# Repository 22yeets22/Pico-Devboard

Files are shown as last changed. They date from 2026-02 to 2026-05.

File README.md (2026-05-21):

<h1 align="center">
  Pico+ Devboard
  <br>
</h1>

<h4 align="center">
A pico sized custom rp2040 devboard, but with 16MB flash and a lot of extra features!
</h4>
<br>

<div align="center">
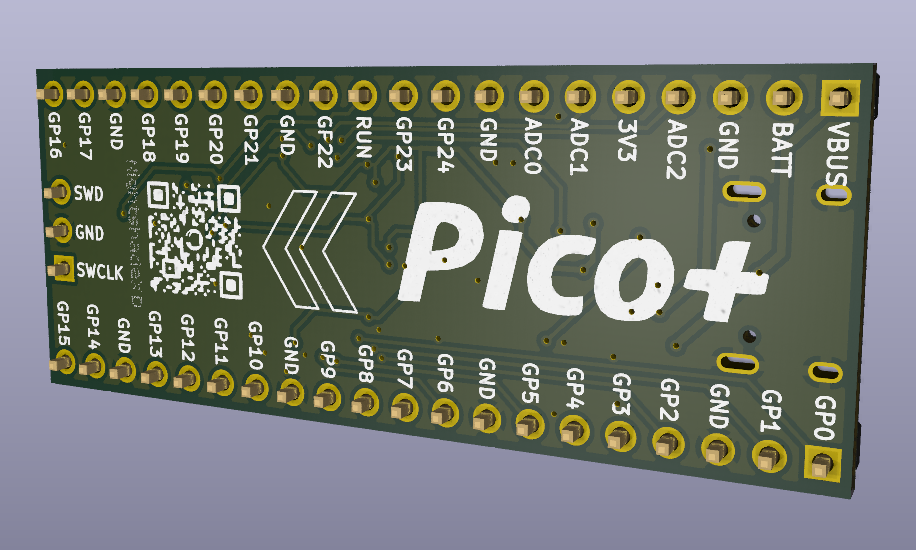
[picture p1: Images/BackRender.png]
Back Render


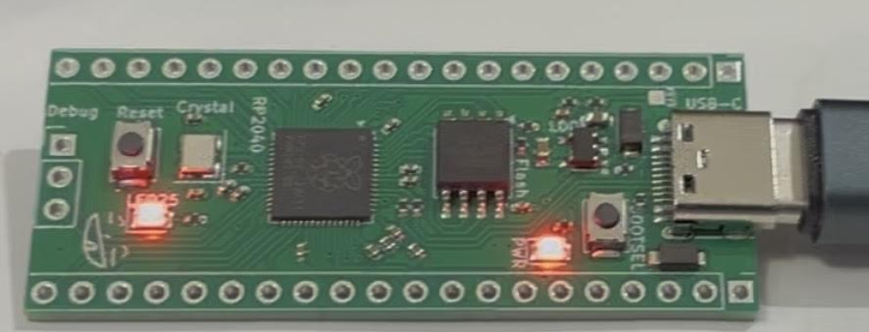
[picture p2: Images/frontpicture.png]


| Front Render | PCB |
| --- | --- |
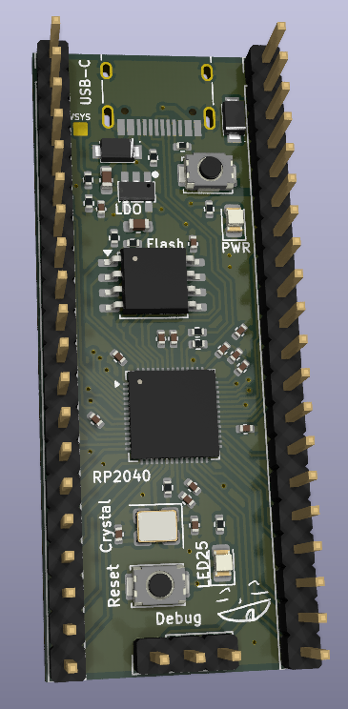
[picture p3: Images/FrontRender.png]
Front Render
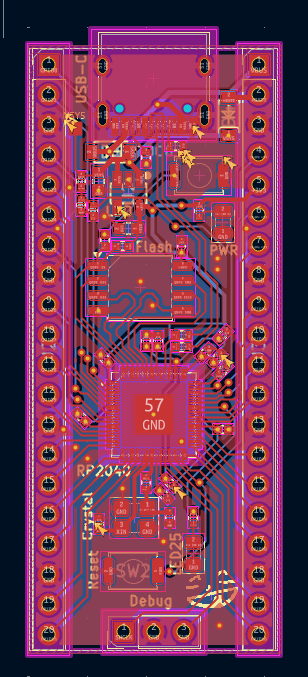
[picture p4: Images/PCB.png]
PCB
|  |  |

</div>

## Motivation

I wanted a more capable RP2040 board with significantly more flash memory and USB-C. Most dev boards limit storage and input options, so I designed one that supports USB-C, battery input, higher current capability, and voltage monitoring while staying in the same form factor.

## Features

- RP2040 microcontroller
- 16MB QSPI Flash
- USB-C
- Battery input (Schottky diode OR-ing with USB)
- 500mA LDO (10V max input)
- VSYS voltage monitoring via resistor divider on ADC3
- Onboard power LED
- Onboard GPIO25 LED
- Bootsel + Reset button
- Fully labeled GPIO pins

## Future Improvements

- Buck-boost regulator for better efficiency + larger voltage range
- Exposed VSYS pin
- 3V3_EN pin breakout

## How to Use

Like a normal Pico:

1. Power the board via USB-C or VBAT input.
2. Flash firmware using BOOTSEL mode (or make your own)
3. Use onboard GPIO headers as you would with a standard Pico.

## Firmware

Untested waveshare 16mb - not my firmware, but has similar specs, so should work fine. Runs circuitpython.

## BOM

A complete `BOM.csv` with direct links is provided in BOM.csv in the root directory.
| Designator | Comment | Footprint | Manufacturer | Part Number | JLCPCB Part # | Link | Qty | Total Price ($) |
|---|---|---|---|---|---|---|-----|---|
| C1, C4 | 1uF | 0402 | Samsung | CL05A105KA5NQNC | C52923 | https://jlcpcb.com/partdetail/53938-CL05A105KA5NQNC/C52923 | 10 | 0.033 |
| C9 | 1nF | 0402 | FH | 0402B102K500NT | C1523 | https://jlcpcb.com/partdetail/1875-0402B102K500NT/C1523 | 5 | 0.006 |
| C11, C8, C3, C10, C17, C5, C7, C6, C12, C2 | 0.1uF | 0402 | Samsung | CL05B104KO5NNNC | C1525 | https://jlcpcb.com/partdetail/1877-CL05B104KO5NNNC/C1525 | 50 | 0.065 |
| C14, C13 | 10uF | 0603 | Samsung | CL10A106KP8NNNC | C19702 | https://jlcpcb.com/partdetail/20411-CL10A106KP8NNNC/C19702 | 10 | 0.065 |
| C16, C15 | 33pF | 0402 | FH | 0402CG330J500NT | C1562 | https://jlcpcb.com/partdetail/1914-0402CG330J500NT/C1562 | 10 | 0.012 |
| D2, D1 | LED (Red 0805) | 0805 | NationStar | NCD0805R1 | C84256 | https://jlcpcb.com/partdetail/85425-NCD0805R1/C84256 | 10 | 0.131 |
| D4, D3 | FMBR120VLSFT1G | SOD-123FL | FUXINSEMI | FMBR120VLSFT1G | C48677824 | https://jlcpcb.com/partdetail/FUXINSEMI-FMBR120VLSFT1G/C48677824 | 14 | 1.0444 |
| J1 | USB-C 14P | SMD | Hroparts | TYPE-C-31-M-12 | C165948 | https://jlcpcb.com/partdetail/Korean_HropartsElec-TYPE_C_31_M12/C165948 | 5 | 0.9055 |
| R1, R2 | 5.1K | 0402 | UNI-ROYAL | 0402WGF5101TCE | C25905 | https://jlcpcb.com/partdetail/26648-0402WGF5101TCE/C25905 | 10 | 0.008 |
| R4, R3 | 27Ω | 0402 | UNI-ROYAL | 0402WGF270JTCE | C25100 | https://jlcpcb.com/partdetail/25843-0402WGF270JTCE/C25100 | 22 | 0.0154 |
| R7 | 10K | 0402 | UNI-ROYAL | 0402WGF1002TCE | C25744 | https://jlcpcb.com/partdetail/26487-0402WGF1002TCE/C25744 | 5 | 0.004 |
| R9, R8, R5, R6 | 1K | 0402 | UNI-ROYAL | 0402WGF1001TCE | C11702 | https://jlcpcb.com/partdetail/12256-0402WGF1001TCE/C11702 | 20 | 0.014 |
| R10 | 200K | 0402 | UNI-ROYAL | 0402WGF2003TCE | C25764 | https://jlcpcb.com/partdetail/26507-0402WGF2003TCE/C25764 | 5 | 0.0035 |
| R11 | 100K | 0402 | UNI-ROYAL | 0402WGF1003TCE | C25741 | https://jlcpcb.com/partdetail/26484-0402WGF1003TCE/C25741 | 5 | 0.004 |
| SW2, SW1 | Tactile Switch | 4x3mm SMD | XUNPU | TS-1088-AR02016 | C720477 | https://jlcpcb.com/partdetail/XUNPU-TS_1088AR02016/C720477 | 10 | 0.476 |
| U1 | RP2040 | LQFN-56 | Raspberry Pi | RP2040 | C2040 | https://jlcpcb.com/partdetail/RaspberryPi-RP2040/C2040 | 5 | 4.827 |
| U2 | TPSPX3819M5-L-3-3 | SOT-23-5 | TECH PUBLIC | TPSPX3819M5-L-3-3 | C5370980 | https://jlcpcb.com/partdetail/TECHPUBLIC-TPSPX3819M5_L_33/C5370980 | 7 | 0.6839 |
| U3 | W25Q128JVSIQ | SOIC-8-208mil | Winbond | W25Q128JVSIQ | C97521 | https://jlcpcb.com/partdetail/WinbondElec-W25Q128JVSIQ/C97521 | 5 | 11.637 |
| Y1 | 12MHz Crystal | SMD3225-4P | YXC | X322512MSB4SI | C9002 | https://jlcpcb.com/partdetail/YXC_CrystalOscillators-X322512MSB4SI/C9002 | 5 | 0.363 |
| J3, J2 | 1x20 Pin Header | P2.54mm | — | Not Selected | — | — | — | — |
| J4 | 1x03 Pin Header | P2.54mm | — | Not Selected | — | — | — | — |

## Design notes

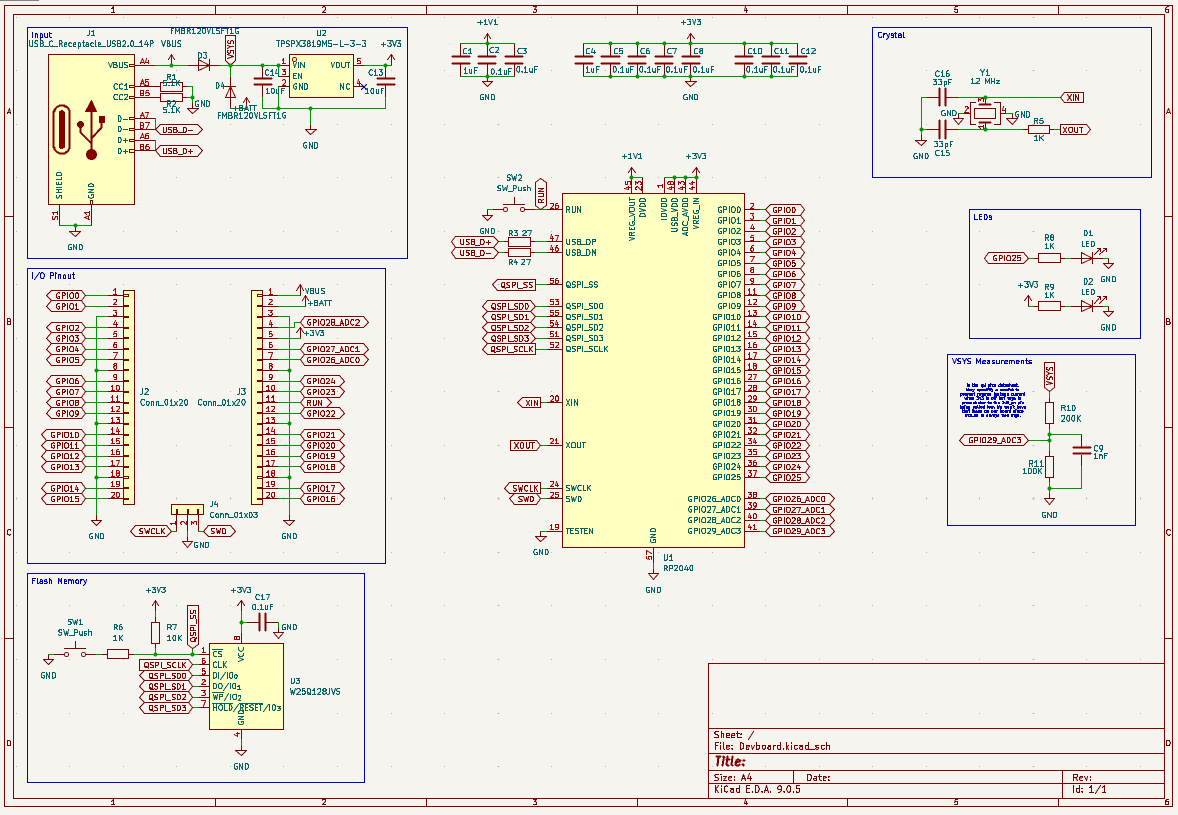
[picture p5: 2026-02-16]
Images/Schematic.png

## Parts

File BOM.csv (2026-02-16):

Id | Designator | Footprint | Quantity | Comment | Supplier and ref
1 | SW2,SW1 | SW_Push_SPST_NO_Alps_SKRK | 2 | SW_Push
2 | C16,C15 | C_0402_1005Metric | 2 | 33pF
3 | U2 | SOT-23-5_L3.0-W1.6-P0.95-LS2.8-BR | 1 | TPSPX3819M5-L-3-3
4 | R11 | R_0402_1005Metric | 1 | 100K
5 | R10 | R_0402_1005Metric | 1 | 200K
6 | D4,D3 | SOD-123FL_L2.8-W1.8-LS3.8-RD | 2 | FMBR120VLSFT1G
7 | C9 | C_0402_1005Metric | 1 | 1nF
8 | J1 | USB_C_Receptacle_HRO_TYPE-C-31-M-12 | 1 | USB_C_Receptacle_USB2.0_14P
9 | C11,C8,C3,C10,C17,C5,C7,C6,C12,C2 | C_0402_1005Metric | 10 | 0.1uF
10 | R4,R3 | R_0402_1005Metric | 2 | 27
11 | C1,C4 | C_0402_1005Metric | 2 | 1uF
12 | R1,R2 | R_0402_1005Metric | 2 | 5.1K
13 | J4 | PinHeader_1x03_P2.54mm_Vertical | 1 | Conn_01x03
14 | C14,C13 | C_0603_1608Metric | 2 | 10uF
15 | D2,D1 | LED_0805_2012Metric | 2 | LED
16 | R7 | R_0402_1005Metric | 1 | 10K
17 | R9,R8,R5,R6 | R_0402_1005Metric | 4 | 1K
18 | J3,J2 | PinHeader_1x20_P2.54mm_Vertical | 2 | Conn_01x20
19 | Y1 | Crystal_SMD_3225-4Pin_3.2x2.5mm | 1 | 12 MHz
20 | U1 | QFN-56-1EP_7x7mm_P0.4mm_EP3.2x3.2mm | 1 | RP2040
21 | U3 | SOIC-8_5.3x5.3mm_P1.27mm | 1 | W25Q128JVS

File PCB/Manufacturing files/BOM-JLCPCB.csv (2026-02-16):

JLCPCB BOM Tool - BOM Matching
BOM name?Devboard-JLCPCB Assembly Order.xlsx |  |  | Download Time?2026-02-16 22:46:35 |  |  |  | * Our matching results are updated in real-time, but stock and prices may change. If it's been over 24 hours, please re-match before placing your order.
PCB Assembled Qty?5 |  |  | Est. Total Price?20.2977
Your BOM |  |  |  |  | Matched Parts |  |  |  |  |  |  | Order Information
Top Designator | Bottom Designator | Comment | Footprint | JLCPCB Part # | Matches | Part # | Manufacturer | Footprint | Description | Category | Warning | JLCPCB Part # | Product link | Lib Type | Qty | Source | Total Price ($)
C1,C4 |  | 1uF | C_0402_1005Metric |  | Select by Customer | CL05A105KA5NQNC | Samsung Electro-Mechanics | 0402 | 1uF 25V X5R ±10% 0402 Multilayer Ceramic Capacitors MLCC - SMD/SMT ROHS | Multilayer Ceramic Capacitors MLCC - SMD/SMT |  | C52923 | https://jlcpcb.com/partdetail/53938-CL05A105KA5NQNC/C52923 | Basic | 10 | 10 JLCPCB | 0.033
C9 |  | 1nF | C_0402_1005Metric |  | Select by Customer | 0402B102K500NT | FH (Guangdong Fenghua Advanced Tech) | 0402 | 1nF 50V X7R ±10% 0402 Multilayer Ceramic Capacitors MLCC - SMD/SMT ROHS | Multilayer Ceramic Capacitors MLCC - SMD/SMT |  | C1523 | https://jlcpcb.com/partdetail/1875-0402B102K500NT/C1523 | Basic | 5 | 5 JLCPCB | 0.006
C11,C8,C3,C10,C17,C5,C7,C6,C12,C2 |  | 0.1uF | C_0402_1005Metric |  | Select by Customer | CL05B104KO5NNNC | Samsung Electro-Mechanics | 0402 | 100nF 16V X7R ±10% 0402 Multilayer Ceramic Capacitors MLCC - SMD/SMT ROHS | Multilayer Ceramic Capacitors MLCC - SMD/SMT | 1.The comment (CL05B104KO5NNNC) of this part does not match the one (0.1uF) provided in your BOM. Please confirm; | C1525 | https://jlcpcb.com/partdetail/1877-CL05B104KO5NNNC/C1525 | Basic | 50 | 50 JLCPCB | 0.065
C14,C13 |  | 10uF | C_0603_1608Metric |  | Select by Customer | CL10A106KP8NNNC | Samsung Electro-Mechanics | 0603 | 10V 10uF X5R ±10% 0603 Multilayer Ceramic Capacitors MLCC - SMD/SMT ROHS | Multilayer Ceramic Capacitors MLCC - SMD/SMT |  | C19702 | https://jlcpcb.com/partdetail/20411-CL10A106KP8NNNC/C19702 | Basic | 10 | 10 JLCPCB | 0.065
C16,C15 |  | 33pF | C_0402_1005Metric |  | Select by Customer | 0402CG330J500NT | FH (Guangdong Fenghua Advanced Tech) | 0402 | 33pF 50V C0G ±5% 0402 Multilayer Ceramic Capacitors MLCC - SMD/SMT ROHS | Multilayer Ceramic Capacitors MLCC - SMD/SMT |  | C1562 | https://jlcpcb.com/partdetail/1914-0402CG330J500NT/C1562 | Basic | 10 | 10 JLCPCB | 0.012
D2,D1 |  | LED | LED_0805_2012Metric |  | Select by Customer | NCD0805R1 | Foshan NationStar Optoelectronics | 0805 | -30?~+85? 1.6V~2.6V 130° 195mcd 25mA 615nm~630nm 630nm 65mW Discrete Diode Red 0805 LED Indication - Discrete ROHS | LED Indication - Discrete | 1.The comment (NCD0805R1) of this part does not match the one (LED) provided in your BOM. Please confirm; | C84256 | https://jlcpcb.com/partdetail/85425-NCD0805R1/C84256 | Basic | 10 | 10 JLCPCB | 0.131
D4,D3 |  | FMBR120VLSFT1G | SOD-123FL_L2.8-W1.8-LS3.8-RD |  | Select by System | FMBR120VLSFT1G | FUXINSEMI | SOD-123FL | -55?~+125? 1A 200uA 20V 380mV@1.0A 45A SOD-123FL Super Barrier Rectifiers (SBR) ROHS | Super Barrier Rectifiers (SBR) |  | C48677824 | https://jlcpcb.com/partdetail/FUXINSEMI-FMBR120VLSFT1G/C48677824 | Extended | 14 | 14 JLCPCB | 1.0444
J1 |  | USB_C_Receptacle_USB2.0_14P | USB_C_Receptacle_HRO_TYPE-C-31-M-12 |  | Select by Customer | TYPE-C-31-M-12 | Korean Hroparts Elec | SMD | -30?~+80? 1 10,000 cycles 16P 20V 5A 7.35mm Female Surface Mount, Right Angle Type-C SMD USB Connectors ROHS | USB Connectors |  | C165948 | https://jlcpcb.com/partdetail/Korean_HropartsElec-TYPE_C_31_M12/C165948 | Extended | 5 | 5 JLCPCB | 0.9055
R1,R2 |  | 5.1K | R_0402_1005Metric |  | Select by Customer | 0402WGF5101TCE | UNI-ROYAL(Uniroyal Elec) | 0402 | -55?~+155? 5.1k? 50V 62.5mW Thick Film Resistor ±1% ±100ppm/? 0402 Chip Resistor - Surface Mount ROHS | Chip Resistor - Surface Mount |  | C25905 | https://jlcpcb.com/partdetail/26648-0402WGF5101TCE/C25905 | Basic | 10 | 10 JLCPCB | 0.008
R4,R3 |  | 27 | R_0402_1005Metric |  | Select by Customer | 0402WGF270JTCE | UNI-ROYAL(Uniroyal Elec) | 0402 | -55?~+155? 27? 50V 62.5mW Thick Film Resistor ±1% ±100ppm/? 0402 Chip Resistor - Surface Mount ROHS | Chip Resistor - Surface Mount | 1.The comment (0402WGF270JTCE) of this part does not match the one (27) provided in your BOM. Please confirm; | C25100 | https://jlcpcb.com/partdetail/25843-0402WGF270JTCE/C25100 | Extended | 22 | 22 JLCPCB | 0.0154
R7 |  | 10K | R_0402_1005Metric |  | Select by Customer | 0402WGF1002TCE | UNI-ROYAL(Uniroyal Elec) | 0402 | -55?~+155? 10k? 50V 62.5mW Thick Film Resistor ±1% ±100ppm/? 0402 Chip Resistor - Surface Mount ROHS | Chip Resistor - Surface Mount | 1.The comment (0402WGF1002TCE) of this part does not match the one (10K) provided in your BOM. Please confirm; | C25744 | https://jlcpcb.com/partdetail/26487-0402WGF1002TCE/C25744 | Basic | 5 | 5 JLCPCB | 0.004
R9,R8,R5,R6 |  | 1K | R_0402_1005Metric |  | Select by Customer | 0402WGF1001TCE | UNI-ROYAL(Uniroyal Elec) | 0402 | -55?~+155? 1k? 50V 62.5mW Thick Film Resistor ±1% ±100ppm/? 0402 Chip Resistor - Surface Mount ROHS | Chip Resistor - Surface Mount | 1.The comment (0402WGF1001TCE) of this part does not match the one (1K) provided in your BOM. Please confirm; | C11702 | https://jlcpcb.com/partdetail/12256-0402WGF1001TCE/C11702 | Basic | 20 | 20 JLCPCB | 0.014
R10 |  | 200K | R_0402_1005Metric |  | Select by Customer | 0402WGF2003TCE | UNI-ROYAL(Uniroyal Elec) | 0402 | -55?~+155? 200k? 50V 62.5mW Thick Film Resistor ±1% ±100ppm/? 0402 Chip Resistor - Surface Mount ROHS | Chip Resistor - Surface Mount | 1.The comment (0402WGF2003TCE) of this part does not match the one (200K) provided in your BOM. Please confirm; | C25764 | https://jlcpcb.com/partdetail/26507-0402WGF2003TCE/C25764 | Basic | 5 | 5 JLCPCB | 0.0035
R11 |  | 100K | R_0402_1005Metric |  | Select by Customer | 0402WGF1003TCE | UNI-ROYAL(Uniroyal Elec) | 0402 | -55?~+155? 100k? 50V 62.5mW Thick Film Resistor ±1% ±100ppm/? 0402 Chip Resistor - Surface Mount ROHS | Chip Resistor - Surface Mount | 1.The comment (0402WGF1003TCE) of this part does not match the one (100K) provided in your BOM. Please confirm; | C25741 | https://jlcpcb.com/partdetail/26484-0402WGF1003TCE/C25741 | Basic | 5 | 5 JLCPCB | 0.004
SW2,SW1 |  | SW_Push | SW_Push_SPST_NO_Alps_SKRK |  | Select by Customer | TS-1088-AR02016 | XUNPU | SMD,4x3mm | -30?~+80? 1.6N 100,000 Cycles 12V 2mm 3mm 4mm 50mA Black Round Button SMD(SMT) Tab SPST Surface Mount,Vertical Without Bracket SMD,4x3mm Tactile Switches ROHS | Tactile Switches |  | C720477 | https://jlcpcb.com/partdetail/XUNPU-TS_1088AR02016/C720477 | Basic | 10 | 10 JLCPCB | 0.476
U1 |  | RP2040 | QFN-56-1EP_7x7mm_P0.4mm_EP3.2x3.2mm |  | Select by Customer | RP2040 | Raspberry Pi | LQFN-56(7x7) | 12bit 133MHz 30 LQFN-56(7x7) Microcontrollers (MCU/MPU/SOC) ROHS | Microcontrollers (MCU/MPU/SOC) |  | C2040 | https://jlcpcb.com/partdetail/RaspberryPi-RP2040/C2040 | Extended | 5 | 5 JLCPCB | 4.827
U2 |  | TPSPX3819M5-L-3-3 | SOT-23-5_L3.0-W1.6-P0.95-LS2.8-BR |  | Select by System | TPSPX3819M5-L-3-3 | TECH PUBLIC | SOT-23-5 | -40?~+125?@(Tj) 1 20V 3.3V 420mV@(100mA) 500mA 5uA 70dB@(1kHz) Fixed Over Current Protection?Over Temperature Protection?Enable Positive SOT-23-5 Voltage Regulators - Linear, Low Drop Out (LDO) Regulators ROHS | Voltage Regulators - Linear, Low Drop Out (LDO) Regulators |  | C5370980 | https://jlcpcb.com/partdetail/TECHPUBLIC-TPSPX3819M5_L_33/C5370980 | Extended | 7 | 7 JLCPCB | 0.6839
U3 |  | W25Q128JVS | SOIC-8_5.3x5.3mm_P1.27mm |  | Select by Customer | W25Q128JVSIQ | Winbond Elec | SOIC-8-208mil | -40?~+85? 100,000 Cycles 120ms@(32KB) 128Mbit 133MHz 1uA 2.7V~3.6V 20 Years 3ms SPI SOIC-8-208mil NOR FLASH ROHS | NOR FLASH | 1.The comment (W25Q128JVSIQ) of this part does not match the one (W25Q128JVS) provided in your BOM. Please confirm; | C97521 | https://jlcpcb.com/partdetail/WinbondElec-W25Q128JVSIQ/C97521 | Basic | 5 | 5 JLCPCB | 11.637
Y1 |  | 12MHz | Crystal_SMD_3225-4Pin_3.2x2.5mm |  | Select by Customer | X322512MSB4SI | YXC Crystal Oscillators | SMD3225-4P | -40?~+85? 12MHz 20pF Crystal Oscillator ±10ppm ±20ppm SMD3225-4P Crystals ROHS | Crystals |  | C9002 | https://jlcpcb.com/partdetail/YXC_CrystalOscillators-X322512MSB4SI/C9002 | Basic | 5 | 5 JLCPCB | 0.363
J3,J2 |  | Conn_01x20 | PinHeader_1x20_P2.54mm_Vertical |  | No matches | No Part Selected
J4 |  | Conn_01x03 | PinHeader_1x03_P2.54mm_Vertical |  | No matches | No Part Selected

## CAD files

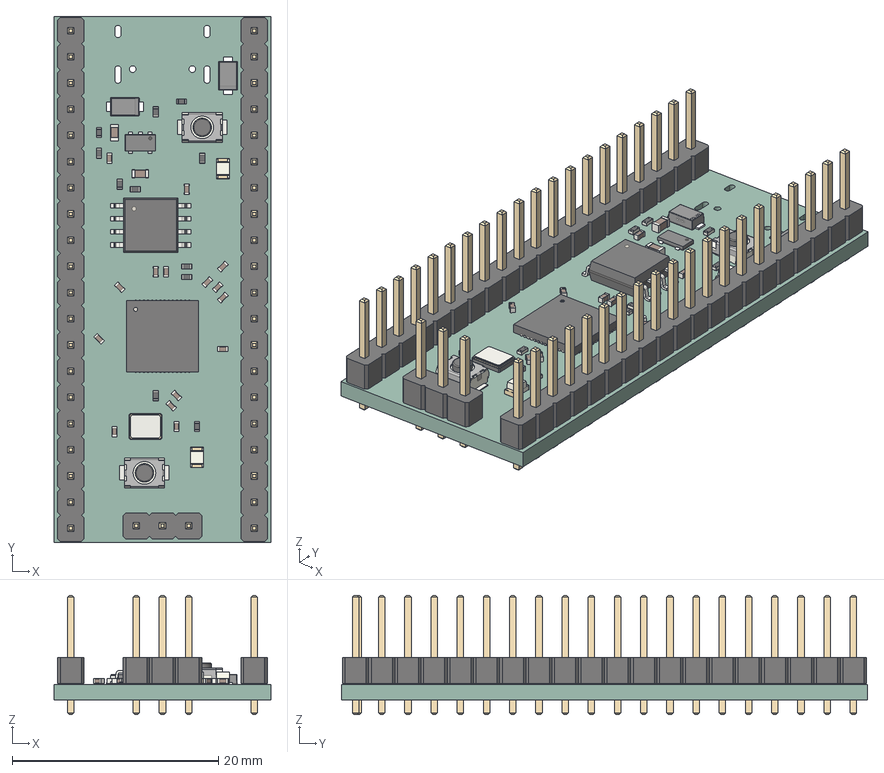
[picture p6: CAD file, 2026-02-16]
Devboard.step
21.0 x 51.0 x 11.5 mm
C_0402_1005Metric x 15
SOD-123FL_L2.8-W1.8-LS3.8-RD x 2
R_0402_1005Metric x 11
PinHeader_1x03_P2.54mm_Vertical
C_0603_1608Metric x 2
LED_0805_2012Metric x 2
SOT-23-5_L3.0-W1.6-P0.95-LS2.8-BR
SW_Push_SPST_NO_Alps_SKRK x 2
PinHeader_1x20_P2.54mm_Vertical x 2
Crystal_SMD_3225-4Pin_3.2x2.5mm
QFN-56-1EP_7x7mm_P0.4mm_EP3.2x3.2mm
SOIC-8_5.3x5.3mm_P1.27mm
Devboard_PCB

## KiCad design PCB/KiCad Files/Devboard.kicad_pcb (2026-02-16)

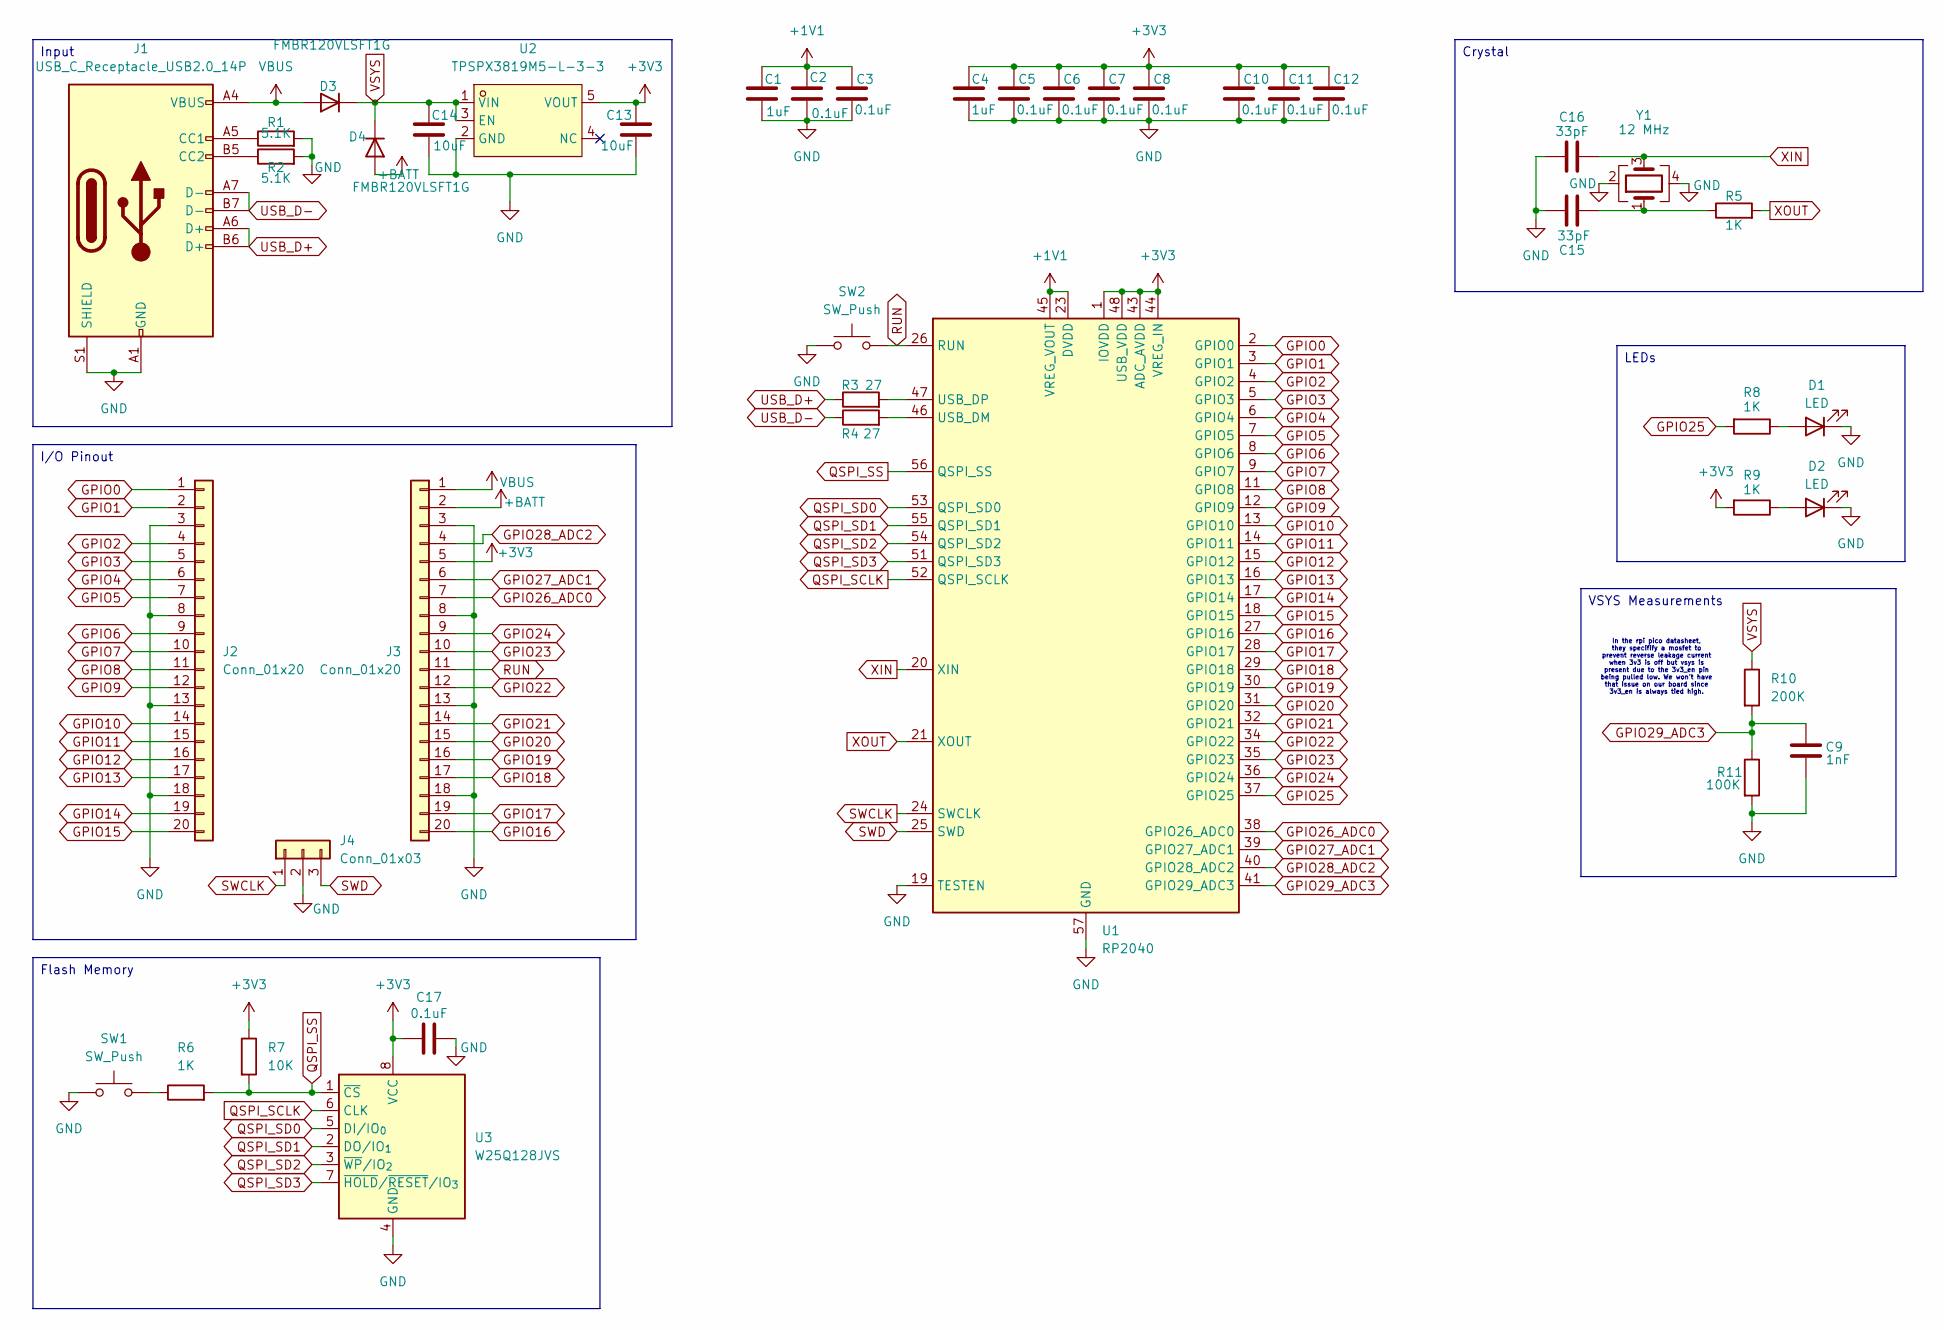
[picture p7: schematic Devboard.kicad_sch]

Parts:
C1, C4: 1uF; C_0402_1005Metric
C2, C3, C5, C6, C7, C8, C10, C11, C12, C17: 0.1uF; C_0402_1005Metric
C9: 1nF; C_0402_1005Metric
C13, C14: 10uF; C_0603_1608Metric
C15, C16: 33pF; C_0402_1005Metric
D1, D2: LED; LED_0805_2012Metric
D3, D4: FMBR120VLSFT1G; SOD-123FL_L2.8-W1.8-LS3.8-RD
J1: USB_C_Receptacle_USB2.0_14P; USB_C_Receptacle_HRO_TYPE-C-31-M-12
J2, J3: Conn_01x20; PinHeader_1x20_P2.54mm_Vertical
J4: Conn_01x03; PinHeader_1x03_P2.54mm_Vertical
R1, R2: 5.1K; R_0402_1005Metric
R3, R4: 27; R_0402_1005Metric
R5, R6, R8, R9: 1K; R_0402_1005Metric
R7: 10K; R_0402_1005Metric
R10: 200K; R_0402_1005Metric
R11: 100K; R_0402_1005Metric
SW1, SW2: SW_Push; SW_Push_SPST_NO_Alps_SKRK
U1: RP2040; QFN-56-1EP_7x7mm_P0.4mm_EP3.2x3.2mm
U2: TPSPX3819M5-L-3-3; SOT-23-5_L3.0-W1.6-P0.95-LS2.8-BR; LCSC Part C5370980
U3: W25Q128JVS; SOIC-8_5.3x5.3mm_P1.27mm
Y1: 12 MHz; Crystal_SMD_3225-4Pin_3.2x2.5mm

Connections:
+1V1: C1.1, C2.1, C3.1, U1.23 (DVDD), U1.45 (VREG_VOUT), U1.50 (DVDD)
+3V3: C4.1, C5.1, C6.1, C7.1, C8.1, C10.1, C11.1, C12.1, C13.1, C17.1, J3.5, R7.1, R9.2, U1.1 (IOVDD), U1.10 (IOVDD), U1.22 (IOVDD), U1.33 (IOVDD), U1.42 (IOVDD), U1.43 (ADC_AVDD), U1.44 (VREG_IN), U1.48 (USB_VDD), U1.49 (IOVDD), U2.5 (VOUT), U3.8 (VCC)
+BATT: D4.2 (A), J3.2
GND: C1.2, C2.2, C3.2, C4.2, C5.2, C6.2, C7.2, C8.2, C9.2, C10.2, C11.2, C12.2, C13.2, C14.2, C15.1, C16.1, C17.2, D1.1 (K), D2.1 (K), J1.A1 (GND), J1.A12 (GND), J1.B1 (GND), J1.B12 (GND), J1.S1 (SHIELD), J2.3, J2.8, J2.13, J2.18, J3.3, J3.8, J3.13, J3.18, J4.2, R1.2, R2.2, R11.2, SW1.1, SW2.2, U1.19 (TESTEN), U1.57 (GND), U2.2 (GND), U3.4 (GND), Y1.2, Y1.4
GPIO0: J2.1, U1.2 (GPIO0)
GPIO1: J2.2, U1.3 (GPIO1)
GPIO2: J2.4, U1.4 (GPIO2)
GPIO3: J2.5, U1.5 (GPIO3)
GPIO4: J2.6, U1.6 (GPIO4)
GPIO5: J2.7, U1.7 (GPIO5)
GPIO6: J2.9, U1.8 (GPIO6)
GPIO7: J2.10, U1.9 (GPIO7)
GPIO8: J2.11, U1.11 (GPIO8)
GPIO9: J2.12, U1.12 (GPIO9)
GPIO10: J2.14, U1.13 (GPIO10)
GPIO11: J2.15, U1.14 (GPIO11)
GPIO12: J2.16, U1.15 (GPIO12)
GPIO13: J2.17, U1.16 (GPIO13)
GPIO14: J2.19, U1.17 (GPIO14)
GPIO15: J2.20, U1.18 (GPIO15)
GPIO16: J3.20, U1.27 (GPIO16)
GPIO17: J3.19, U1.28 (GPIO17)
GPIO18: J3.17, U1.29 (GPIO18)
GPIO19: J3.16, U1.30 (GPIO19)
GPIO20: J3.15, U1.31 (GPIO20)
GPIO21: J3.14, U1.32 (GPIO21)
GPIO22: J3.12, U1.34 (GPIO22)
GPIO23: J3.10, U1.35 (GPIO23)
GPIO24: J3.9, U1.36 (GPIO24)
GPIO25: R8.2, U1.37 (GPIO25)
GPIO26_ADC0: J3.7, U1.38 (GPIO26_ADC0)
GPIO27_ADC1: J3.6, U1.39 (GPIO27_ADC1)
GPIO28_ADC2: J3.4, U1.40 (GPIO28_ADC2)
GPIO29_ADC3: C9.1, R10.2, R11.1, U1.41 (GPIO29_ADC3)
unnamed: C15.2, R5.1, Y1.1
unnamed: D1.2 (A), R8.1
unnamed: D2.2 (A), R9.1
unnamed: J1.A5 (CC1), R1.1
unnamed: J1.B5 (CC2), R2.1
unnamed: R6.1, SW1.2
unnamed: R4.2, U1.46 (USB_DM)
unnamed: R3.2, U1.47 (USB_DP)
QSPI_SCLK: U1.52 (QSPI_SCLK), U3.6 (CLK)
QSPI_SD0: U1.53 (QSPI_SD0), U3.5 (DI/IO_{0})
QSPI_SD1: U1.55 (QSPI_SD1), U3.2 (DO/IO_{1})
QSPI_SD2: U1.54 (QSPI_SD2), U3.3 (~WP/IO_{2})
QSPI_SD3: U1.51 (QSPI_SD3), U3.7 (~HOLD/~RESET/IO_{3})
QSPI_SS: R6.2, R7.2, U1.56 (QSPI_SS), U3.1 (~CS)
RUN: J3.11, SW2.1, U1.26 (RUN)
SWCLK: J4.1, U1.24 (SWCLK)
SWD: J4.3, U1.25 (SWD)
USB_D+: J1.A6 (D+), J1.B6 (D+), R3.1
USB_D-: J1.A7 (D-), J1.B7 (D-), R4.1
VBUS: D3.2 (A), J1.A4 (VBUS), J1.A9 (VBUS), J1.B4 (VBUS), J1.B9 (VBUS), J3.1
VSYS: C14.1, D3.1 (K), D4.1 (K), R10.1, U2.1 (VIN), U2.3 (EN)
XIN: C16.2, U1.20 (XIN), Y1.3
XOUT: R5.2, U1.21 (XOUT)

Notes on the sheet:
In the rpi pico datasheet, they specifify a mosfet to prevent reverse leakage current when 3v3 is off but vsys is present due to the 3v3_en pin being pulled low. We won't have that issue on our board since 3v3_en is always tied high.
Input
LEDs
VSYS Measurements
Flash Memory
I/O Pinout
Crystal

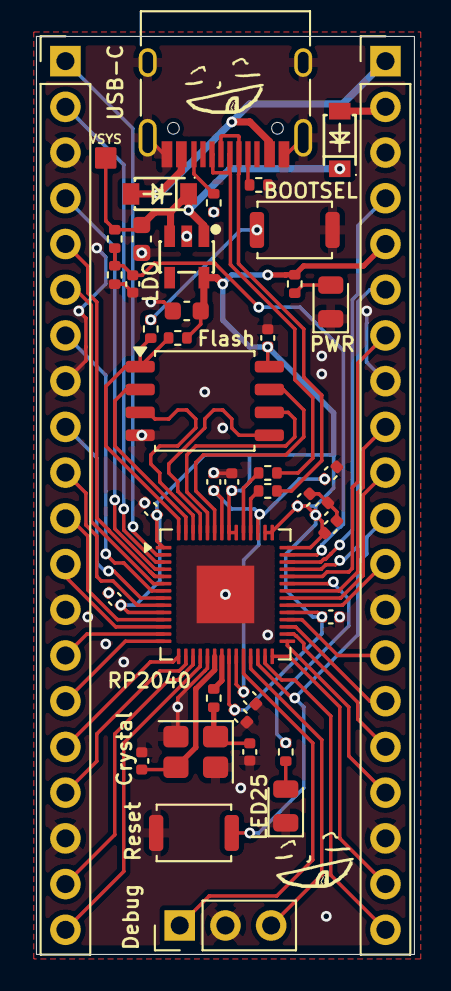
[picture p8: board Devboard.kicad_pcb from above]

Board: 2 copper layers, 21.0 x 51.0 mm, 42 parts (0 on the bottom side), 57 nets.

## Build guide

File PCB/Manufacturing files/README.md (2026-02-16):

## Manufacturing files

- BOM - bill of materials, generated from kicad
- BOM-JLCPCB - bill of materials - with selected parts in JLCPCB
- gerbers - all gerber files
- PickAndPlace - files generated from KiCad
- PickAndPlace-JLCPCB - file tuned for jlcpcb (renamed headers)

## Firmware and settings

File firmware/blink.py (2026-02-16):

# simple code to test if your devboard is even working at all
# blinks the onboard gpio25 led
# circuitpython

import board
import digitalio
import time

led = digitalio.DigitalInOut(board.GP25)  # GPIO25
led.direction = digitalio.Direction.OUTPUT

while True:
    led.value = not led.value  # toggle
    time.sleep(0.5)

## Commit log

2026-02-16 rename - add files
    [BOM-JLCPCB.xls, BOM.csv, Devboard.kicad_pcb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]
2026-02-16 readme fix + 3d model
    [Devboard.step]
2026-02-16 reorganize, readme
    [BOM-JLCPCB.xls, BOM.csv, Devboard.kicad_pcb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]
2026-02-16 new bom
    [BOM-JLCPCB.csv]
2026-02-16 add schematic but not in readme
